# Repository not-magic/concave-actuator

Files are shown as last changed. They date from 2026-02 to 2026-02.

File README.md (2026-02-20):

# Concave Actuator
A 3d printed concave actuator for an IL/Eurostick

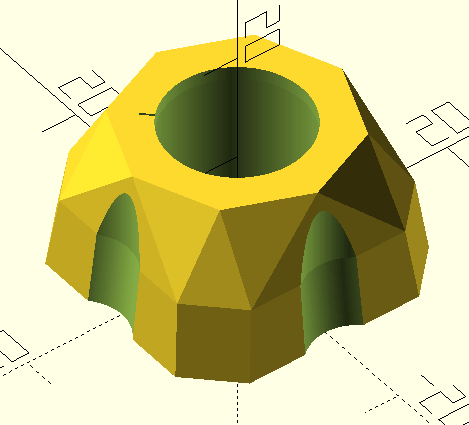
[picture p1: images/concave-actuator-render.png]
Sanwa-style round actuator and square gate


## Why would I want this?

A normal Sanwa-style joystick has plunger switches and a round actuator. If you look at the geometry when it makes contact with the switches, it is more sensitive at cardinal angles, and the activation map looks like this:

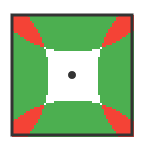
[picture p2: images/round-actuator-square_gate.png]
Sanwa-style round actuator and square gate


This shape complements a square gate, which tends to reflect up and down a little bit when you push against a cardinal angle.

If you install a round gate, you no longer have the same gate reflection, but you have dramatically smaller diagonal areas:

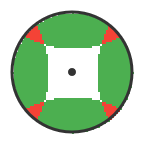
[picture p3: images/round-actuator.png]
Sanwa-style round actuator and round gate


An IL/Eurostick joystick uses a square actuator and a round "collar" which means the activation map looks something like this:

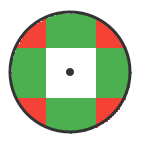
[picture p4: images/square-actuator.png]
Square actuator


(You also get a near identical activation map from a Seimitsu or Korean-lever style with lever switches and a round actuator.)

The idea that prompted this is, what does it look like if we had non-square sides? Using the same actuator simulator making shallow round cutouts in the side you can get an activation map that looks like this:

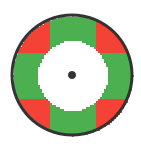
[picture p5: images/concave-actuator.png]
Square actuator


The actual activation area at the cardinals is slightly different because the square actuator is free-spinning which is difficult to simulate, but it "squares" itself whenever it makes contact with two switches.

## Why is this activation area good?

In my time spent tinkering with sticks, the most desirable properties are:

1. Large area diagonals (makes them easy to find)
2. Wide cardinal zones (makes finding cardinals easier and prevents accidental jumps)
3. Shallow cardinal zones (makes dashing faster, taking less time to return to neutral).

These properties are normally in conflict with each other and require balancing that also complements the gate/collar shape and tension. A concave actuator allows the cardinal depth to be controlled independently.

# Releases

In the releases you can find pre-built zip files that have a number of actuator shapes to experiment with, with sizes that show the width and depth of the cutout, as well as some versions for a SLA or FDM printer (FDM printers contain an internal relief slot for seams to go).

In my personal testing I found a width of 6mm and depth of 1mm to feel nice.

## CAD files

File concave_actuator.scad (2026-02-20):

// the outer width (mm) of the actuator in the middle
ACTUATOR_SIZE = 23.4;

// the height of the active area 
ACTUATOR_SWITCH_HEIGHT = 6.4;

// the mm difference between the actuator size at the top and bottom of the active area, to account for the rotation of the stick, so the actuator presses the switch plungers approximately perpendicular
ACTUATOR_SLANT = 1.5;

// The width of the concave cutouts on the side of the actuator
CUTOUT_WIDTH = 6;
// The depth of the concave cutouts on the side of the actuator
CUTOUT_DEPTH = 1.0;

// The total height of the actuator
TOTAL_HEIGHT = 13.5;

// 0 == FDM, 1 == anything else
PRINTER_TYPE = 0;

// The diameter of the stick shaft. If it is too tight and can't spin at all, this needs to be larger. If it has wiggle room it needs to be smaller. This value may need to be tuned for your printer to get it exactly right, I tuned this for a Prusa MK3S+ w/ 0.6mm nozzle.
SHAFT_DIAMETER = 14.0;

function sq(x) = x*x;

AA_BOTTOM_SIZE = ACTUATOR_SIZE + ACTUATOR_SLANT/2;
AA_TOP_SIZE = ACTUATOR_SIZE - ACTUATOR_SLANT/2;

CUTOUT_RADIUS = CUTOUT_DEPTH + (sq(CUTOUT_DEPTH) + sq(CUTOUT_WIDTH/2))/(2*CUTOUT_DEPTH);

module actuator_shape(size, corner_rad)
{	
	difference()
	{	
		hull()
		{
			for (n = [0:3])
			{
				rotate(90*n) translate([size/2-corner_rad, size/2-corner_rad]) circle(corner_rad, $fn=4);
			}
		}
	}
}

module actuator_cutouts()
{
	scale = 1.0;
	radius = CUTOUT_RADIUS;
	inset = CUTOUT_DEPTH;
	
	extra_distance = radius*scale-inset;
	
	for (n = [0:3])
	{
		rotate(90*n) hull() {
			
			translate([AA_TOP_SIZE/2+extra_distance,0,ACTUATOR_SWITCH_HEIGHT]) linear_extrude(10) scale([scale,0.8]) circle(radius, $fn=200);
			translate([AA_BOTTOM_SIZE/2+extra_distance,0,-1]) linear_extrude(1) scale([scale,0.8]) circle(radius, $fn=200);
		}
	}	
}

difference()
{
	CORNER_RAD = 4.0;
	
	union()
	{
		hull()
		{
			translate([0,0,ACTUATOR_SWITCH_HEIGHT]) linear_extrude(0.1) actuator_shape(AA_TOP_SIZE, CORNER_RAD);
			translate([0,0,-1]) linear_extrude(1) actuator_shape(AA_BOTTOM_SIZE, CORNER_RAD);
		
			cylinder(r=SHAFT_DIAMETER/2+3, h=TOTAL_HEIGHT, $fn=8);
		}
		
	}
	
	/*
	difference()
	{
		hull()
		{
			translate([0,0,ACTUATOR_SWITCH_HEIGHT]) linear_extrude(0.1) actuator_shape(AA_TOP_SIZE-4, 2);
			translate([0,0,-1]) linear_extrude(1) actuator_shape(AA_BOTTOM_SIZE-4, 2);
			
			cylinder(r=SHAFT_DIAMETER/2, h=TOTAL_HEIGHT-2, $fn=8);
			
		}
		
		cube([7,100,100], center=true);
		cube([100,7,100], center=true);
		
		cylinder(r=SHAFT_DIAMETER/2+2, h=TOTAL_HEIGHT);
		
	}*/
	
	actuator_cutouts();

	translate([0,0,-1.2]) cylinder(h=TOTAL_HEIGHT, r=SHAFT_DIAMETER/2, $fn=200);
	cylinder(d=12.5, h=100, center=true, $fn=200);
	
	if (PRINTER_TYPE == 0)
	{
		rotate(45) translate([0,2.5,0]) cube([0.2,10, 100], center=true);
	}
	
	translate([0,0,-150]) cube(300, center=true);
}

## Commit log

2026-02-15 Initial check-in
    [concave_actuator.scad]
2026-02-20 Tweaked actuator shape to prevent some friction, added SLA and FDM options
    [concave_actuator.scad]
